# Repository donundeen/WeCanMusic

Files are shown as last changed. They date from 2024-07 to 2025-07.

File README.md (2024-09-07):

# WeCanMusic

WeCanMusic is an open-source hardware and software platform that simplifies the creation of electronic musical instruments from simple found materials and the performance of these instruments by groups of people with no prior musical or performance experience. All sensor input is piped through a system that ensures that the notes produced follow chord changes that can be controlled in real time or composed in advance, allowing integration with live instruments and rock/pop bands. An WeCanMusic Jam Session brings participants together to explore the affordances of low-cost electronic sensors and consider how they can be combined with the materials on hand to create playful objects that generate sound when thrown, touched, bounced, shown colors, etc. These sensors, far from the techno-capitalist ideal of “perfect surveillance devices,” introduce their own noise, flutter and errors, which instead of being corrected, are drawn into dialogue with performers, influencing the aesthetics and acoustics of the performances. Entirely wireless, WeCanMusic performances can happen anywhere, with any number of people, or even with entirely non-human participants. In a new media art world that privileges technical virtuosity, WeCanMusic stubbornly asserts the importance of the amateur, the messy, the joyful. In short, WeCanMusic epowers an entirely different approach to music making, giving everyone a chance to join the jam.

# Included in this repo:

- arduino code to integrate a variety of sensors, on the Arduino Feather ESP32 platform
- Max/MSP patches to control the arduino devices according to a preset-score, and/or a web page allowing real-time chord changes
- NodeJs server which re-implements all Max/MSP features on open-source software, capable of running on a raspberry Pi
- NEW: new arduino code implements the Music Maker (midi synth) Featherwing, so note logic and midi tone production happens on the arduino itself, through attached speakers.
- NEW: Intergration with Pareto Anywhere, allowing the use of Off-the-shelf bluetooth devices as input devices, with audio output through virtual devices running on the server. 

Complete installation instructions coming shortly.

# Live Performances and Media:

- "Paleta De Aguacate, an WeCanMusic Performance", Morelia, Mexico:  https://www.youtube.com/watch?v=Ay2ICAsvL2w&t=2s&ab_channel=DonUndeen 

# In This Repo:

- **arduino**: Arduino files for running on Feather Huzzah ESP32 arduinos. 
  
  - **MaxCompatible**: arduino code for devices that just send thier raw values over UDP to a Max installation (in **PositionalJamAlphaBlast**). I've moved away from this approach to using the more open-source, RPi-based setup in **RPiCompatible**.
  
  - **RPiCompatible**: Arduino code for devices that take their sensor value, turn it into MIDI notes based on the supplied chord changes, and plays the notes using the attached MusicMaker featherwing. It ALSO can send the MIDI note as a makenote message over OSC/UDP, so that another computer could play it via an attached synth. This is useful if you don't have enough MusicMakers, or want to use fancier synths. There will be a sub-folder for each type of device, such as
    
    - **wecanmusic_capacitive**: The version of the device code for handling simple capacitive sensing, on pin 32.
      
      - Note, there are a bunch of files in here, but the only one that should change between types of devices is the one named the same as the folder. All other files should be the same between all devices.
  
  - **Utils:** Useful Utilities
    
    - **curveMaker.maxpat**: sometimes you want to finesse input values in arduino functions, so that an input value is mapped to an output with curve intead of a line, or even a series of curve segments. In this Max patch, you can draw the curve then dump a series of numbers that define the curve, then plug it into the arduino code. **TODO** Build a web interface for drawing curves, or at least selected from a set of pre-created curves.
    
    - **i2c_scanner.ino**:  When working with a bunch of different sensors, sometimes you need to see what i2c channels are in use. That's what this is for
    
    - **SPIFFS_mgmt:** The arduinos use SPIFFS for storing configuration values in non-volative memory. This arduino code helps manage that storage in case things get messy
  
  - **Tests**: Files I made to test things, and may want to refer to later.

- **server**: Files for running the Raspberry Pi server. If you don't need the Local WAP system, then you can run this server code on a Mac, but this setup isn't documented as well. See the README.md file in the **server** folder for installation and usage instructions.

- **VizStudioImplementation**: An implementation of this project that uses Max/MSP for most of the processing. In this setup, the devices simply send their raw values, and Max handles during those values into midi notes according to the chord changes, and sends MIDI values out. In this implmentation, the MIDI values are captured and played by Ableton; the ableton files are also in this folder. I've put aside this version in favor of the more open-source, wireless and headless version using the files in server and arduino folders instead. But there's lots of good stuff in here if you like working with Max.

## Hardware Used:

- Arduino Feather Case, with Battery Case: [Arduino Feather Cases](https://www.tinkercad.com/things/8DuQjJnMVJv-arduino-feather-cases) : this is only slightly modified from the case system created by Adafruit, which you can find here: [Adafruit Feather Box Enclosure by adafruit - Thingiverse](https://www.thingiverse.com/thing:2209964/files). The full assembly instructions and more options for configuration can be found here: [Overview | 3D Printed Case for Adafruit Feather | Adafruit Learning System](https://learn.adafruit.com/3d-printed-case-for-adafruit-feather/) 

- Adafruit HUZZAH32 ESP32 Feather Board: [Adafruit HUZZAH32 – ESP32 Feather ](https://www.adafruit.com/product/3405) 

- Adafruit Music Maker MP3 player and MIDI Synth: [Adafruit Music Maker](https://www.adafruit.com/product/3357) 

- Raspberry Pi 4 (but you can probably use other Pis)

- IQAudio DAC+: Provides much better audio quality than the built-in rpi audio outputs: https://www.pishop.ca/product/iqaudio-dac/ 

#

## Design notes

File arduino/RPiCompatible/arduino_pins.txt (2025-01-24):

/***********************************
Use this is each of the projects in the arduino/RPiCompatible folder
This is an unofficial pinout diagram of the Adafruit Feather Huzza32 (ESP32) board:

https://learn.adafruit.com/adafruit-huzzah32-esp32-feather

For more information about this diagram, see:

https://learn.adafruit.com/adafruit-huzzah32-esp32-feather/pinouts

                                            +-------------------+
                                            | O    | USB |    O |
                                            |      -------   ---|
                                       ~RST | o     3.7/4.2V |  |
                                        3V3 | o  LiPoly Batt |  |
                                         NC | o   USB charge |  |
  config mode button - power switch --- GND | o              ---|
                 power switch---  A0 / DAC2 | o               o | VBAT
                                  A1 / DAC1 | o               o | EN  ------- config mode button
                                    A2 / 34 | o               o | VUSB
                                    A3 / 39 | o               o | 13  / A12 / T4
                                    A4 / 36 | o               o | 12  / A11 / T5
                              T0 /  A5 /  4 | o               o | 27  / A10 / T7
                                   SCK /  5 | o               o | 33  / A9 / T8
                                  MOSI / 18 | o               o | 15  / A8 / T3
                                  MISO / 19 | o               o | 32  / A7 / T9
                                    RX / 16 | o               o | 14  / A6 / T6
                                    TX / 17 | o               o | SCL / 22
                                         21 | o               o | SDA / 23
                                            |                   |
                                            | O               O |
                                            +-------------------+

                             +-----------------------+       
                             | O      | USB |      O |       
                             |        -------        |
                        ~RST | [ ]               |---|
                         3V3 | [ ]               |   | 3.7/4.2V LiPoly Batt (USB charge)
                          NC | [ ]               |---|
                         GND | [ ]                   |
   DAC2 / ADC2 / A0 / GPIO26 | [ ]               [ ] | VBAT / A13
   DAC1 / ADC2 / A1 / GPIO25 | [ ]               [ ] | EN
  NOOUT / ADC1 / A2 / GPIO34 | [ ]               [ ] | VUSB
  NOOUT / ADC1 / A3 / GPIO39 | [ ]               [ ] | GPIO13 / A12 / ADC2 / LED
  NOOUT / ADC1 / A4 / GPIO36 | [ ]               [ ] | GPIO12 / A11 / ADC2
          ADC2 / A5 / GPIO04 | [ ]               [ ] | GPIO27 / A10 / ADC2
                SCK / GPIO05 | [ ]               [ ] | GPIO33 / A9 / ADC1
               MOSI / GPIO18 | [ ]               [ ] | GPIO15 / A8 / ADC2
               MISO / GPIO19 | [ ]               [ ] | GPIO32 / A7 / ADC1
                 RX / GPIO16 | [ ]               [ ] | GPIO14 / A6 / ADC2
                 TX / GPIO17 | [ ]               [ ] | GPIO22 / SCL
                      GPIO21 | [ ]               [ ] | GPIO23 / SDA
                             |                       |
                             | O                   O |
                             +-----------------------+
                             
Power Pins
----------
GND - this is the common ground for all power and logic
BAT - this is the positive voltage to/from the JST jack for the optional Lipoly battery
USB - this is the positive voltage to/from the micro USB jack if connected
EN - this is the 3.3V regulator's enable pin. It's pulled up, so connect to ground to disable the 3.3V regulator
3V - this is the output from the 3.3V regulator. The regulator can supply 500mA peak but half of that is drawn by the ESP32, and it's a fairly power-hungry chip. So if you need a ton of power for stuff like LEDs, motors, etc. Use the USB or BAT pins, and an additional regulator

Logic pins
----------
This is the general purpose I/O pin set for the microcontroller. All logic is 3.3V
The ESP32 runs on 3.3V power and logic, and unless otherwise specified, GPIO pins are not 5V safe!

Serial pins
----------
RX and TX are the additional Serial1 pins, and are not connected to the USB/Serial converter. That means you can use them to connect to UART-devices like GPS's, fingerprint sensors, etc.
The TX pin is the output from the module. The RX pin is the input into the module. Both are 3.3V logic

I2C & SPI pins
----------
You can use the ESP32 to control I2C and SPI devices, sensors, outputs, etc. If using with Arduino, the standard Wire and SPI devices work as you'd expect!
Note that the I2C pins do not have pullup resistors already! You must add them if you want to communicate with an I2C device

GPIO & Analog Pins
----------
GPIO26 - This is also analog input A0 and an analog output DAC2. It uses ADC #2
GPIO25 - This is also analog input A1 and an analog output DAC1. It uses ADC #2
GPIO34 - This is also analog input A2 on ADC #1. Note it is not an output-capable.
GPIO39 - This is also analog input A3 on ADC #1. Note it is not an output-capable.
GPIO36 - This is also analog input A4 on ADC #1. Note it is not an output-capable.
GPIO04 - This is also analog input A5 on ADC #2
GPIO21 - General purpose IO
GPIO13 - This is also an analog input A12 on ADC #2. It's also connected to the red LED next to the USB port
GPIO12 - This is also an analog input A11 on ADC #2. This pin has a pull-down resistor built into it, we recommend using it as an output only, or making sure that the pull-down is not affected during boot.
GPIO27 - This is also an analog input A10 on ADC #2
GPIO33 - This is also an analog input A9 on ADC #1. It can also be used to connect a 32 KHz crystal.
GPIO15 - This is also an analog input A8 on ADC #2
GPIO32 - This is also an analog input A7 on ADC #1. It can also be used to connect a 32 KHz crystal.
GPIO14 - This is also an analog input A6 on ADC #2

There's also an external analog input
A13 - This is general purpose input #35 and also an analog input A13, which is a resistor divider connected to the VBAT line

***********************************/

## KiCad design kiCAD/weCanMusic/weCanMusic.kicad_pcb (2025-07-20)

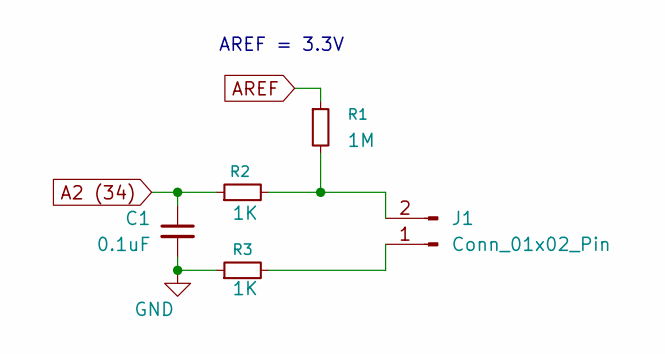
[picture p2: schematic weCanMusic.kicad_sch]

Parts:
C1: 0.1uF; C_0603_1608Metric
J1: Conn_01x02_Pin; PinHeader_1x02_P2.54mm_Vertical
R1: 1M; R_0603_1608Metric
R2, R3: 1K; R_0603_1608Metric

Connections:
A2 (34): C1.1, R2.1
AREF: R1.1
GND: C1.2, R3.1
unnamed: J1.1, R3.2
unnamed: J1.2, R1.2, R2.2

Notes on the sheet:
AREF = 3.3V

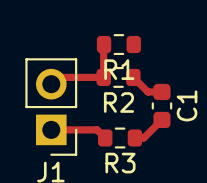
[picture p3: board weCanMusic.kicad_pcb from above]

Board: 2 copper layers, 5 parts (0 on the bottom side), 4 nets.

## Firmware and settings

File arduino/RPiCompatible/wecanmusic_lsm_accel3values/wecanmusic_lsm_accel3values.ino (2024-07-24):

////////////////////////
// NETWORK INCLUDES
/*
 * Required libraries to install in the arduino IDE (use the Library Manager to find and install):
 * https://github.com/Hieromon/PageBuilder : PageBuilder
 * https://github.com/bblanchon/ArduinoJson : ArduinoJson
 * https://github.com/CNMAT/OSC : OSC
 * AutoConnect: https://hieromon.github.io/AutoConnect/index.html : instructions on how to install are here: 
 * follow the instructions under "Install the AutoConnect" if you can't just find it in the Library Manager
 */
// this is all the OSC libraries
#include <SLIPEncodedSerial.h>
#include <OSCData.h>
#include <OSCBundle.h>
#include <OSCBoards.h>
#include <OSCTiming.h>
#include <OSCMessage.h>
#include <OSCMatch.h>
// these the libraries for connecting to WiFi
// based on docs here: https://hieromon.github.io/AutoConnect/gettingstarted.html 
#include <WiFi.h>
// END NETWORK INCLUDES
////////////////////////


// REGEX LIBRARY FOR COMPLEX STRING PARSING
#include <Regexp.h>

// TIMING INCLUDES
#include <AsyncTimer.h> //https://github.com/Aasim-A/AsyncTimer
#include "uClock.h"
// END TIMING INCLUDES

////////////////////////
// CONFIG WEBPAGE INCLUDES
#include <FS.h>                   //this needs to be first, or it all crashes and burns...
#include <WiFiManager.h>          //https://github.com/tzapu/WiFiManager
#ifdef ESP32
  #include <SPIFFS.h>
#endif
#include <ArduinoJson.h>          //https://github.com/bblanchon/ArduinoJson
// END CONFIG WEBPAGE INCLUDES
////////////////////////

// MULTIVALUE SETUP
const int NUM_MULTIVALUES = 3;

////////////////////////////////////
// SENSOR INCLUDES
//gyro code:
// * LSM6DSOX + LIS3MDL FeatherWing : https://www.adafruit.com/product/4565
// * ISM330DHCX + LIS3MDL FeatherWing https://www.adafruit.com/product/4569
// * LSM6DSOX + LIS3MDL Breakout : https://www.adafruit.com/product/4517
// * LSM6DS33 + LIS3MDL Breakout Lhttps://www.adafruit.com/product/4485
// see here: https://learn.adafruit.com/st-9-dof-combo/ard/Users/donundeen/Downloads/TCS3200D/color/color.pdeuino 
/*
 * Libraries to install (include dependencies)
 * OSC
 * Adafruit LSM6DS 
 * Adafruit LIS3MDL
 * AutoConnect (see https://hieromon.github.io/AutoConnect/#installation)
 * 
 */
// SENSOR LIBS/Users/donundeen/Downloads/TCS3200D/TCS3200D/TCS3200D.pde
#include <Adafruit_LSM6DSOX.h>
#include <Adafruit_LIS3MDL.h>
// END SENSOR INCLUDES  
/////////////////////////////////////////

////////////////////////////////
// SENSOR OBJECT CREATION
//Adafruit_LSM6DSOX lsm6ds;
Adafruit_LSM6DSOX lsm6ds;
Adafruit_LIS3MDL lis3mdl;
// END OBJECT CREATION
///////////////////////


///////////////////////////
// DEVICE CONFIGS
// set the accelerometer value to use afor the pitch
// one of:
//    case "gyro.x":
//    case "gyro.y":
//    case "gyro.z":
//    case "accel.x":
//    case "accel.y":
//    case "accel.z":
//    case "mag.x":
//    case "mag.y":
//    case "mag.z":
const int _GYROX = 1;
const int _GYROY = 2;
const int _GYROZ = 3;
const int _ACCELX = 4;
const int _ACCELY = 5;
const int _ACCELZ = 6;
const int _MAGX = 7;
const int _MAGY = 8;
const int _MAGZ = 9;
//int AccelPitchVal[6] = {_GYROX, _GYROY, _GYROZ, _ACCELX, _ACCELY, _ACCELZ}; 
int AccelPitchVal[6] = {_GYROX, _GYROY, _GYROZ, _ACCELX, _ACCELY, _ACCELZ}; 


int SERIALBAUDRATE = 115200;

///////////////////////////////
// MUSIC PERFORMANCE VARIABLES
int notelist[127];
int notelistlength = 0;
int workinglist[6][127]; //MULTIVALUE UPDATE REQUIRED
int workinglistlength[6] = {0,0,0,0,0,0}; //MULTIVALUE UPDATE REQUIRED
// END MUSIC PERFORMANCE VARIABLES
///////////////////////////


// if the device has a synth/speakers attached, set this to true
// if false, it will send a makenote message out over the netework,
// for the server to play.
boolean localSynth = false;

////////////////// SETING UP CONFIG WEBPAGE - FOR WIFI AND OTHER VALUES
//define your default values here, if there are different values in config.json, they are overwritten.
// My values: (in addition to WIFI data)
// wecanmusic_server_ip
// wecanmusic_port
// this_device_name

// wifi autoconnect code
// CONFIG WEBPAGE PINS AND VARS
int resetButtonPin = A0;

char wecanmusic_server_ip[40] = "10.0.0.255";
char wecanmusic_port[6] = "7005";
char this_device_name[16] = "RENAME_ME";
//flag for saving data
bool shouldSaveConfig = true;
/// END SETTING UP CONFIG WEBPAGE VARS
///////////////////////////


/////////////////////////////
// TIMING VARIABLES 
AsyncTimer t;



////////////////////////////////////////////
// NETWORK SPECIFIC VARS - SHOULDN'T CHANGE
/* 
 *  WIFI_MODE_ON set to true to send osc data over WIFI.
 *  When this is true: 
 *  -- if the arduino can't connect to wifi, it will create its own AP, named esp32_ap (pw 12345678)
 *  -- you'll need to connect to that SSID via your phone, and use the interface that pops up on your phone 
 *     to configure the SSID and PW of the router you want to connect to
 *  When WIFI_MODE_ON = false, you need the arduino connected to the laptop, 
 *  and it will send data over serial USB
 */
const boolean WIFI_MODE_ON = true;
/* if we aren't using the auto-configuration process, 
    and we want to hard-code the router's SSID and password here.
    Also set HARDCODE_SSID = true
*/
// remember you can't connect to 5G networks with the arduino. 
bool wifi_connected =false;
/*
 * Sometimes we need to delete the SSIDs that are stored in the config of the arduino.
 * Set this value to TRUE and rerun the arduino, to remove all the stored SSIDs 
 * (aka clear the configuration storage). 
 * Then set it badk to false to start saving new SSID/Passwords
 * 
 */
const boolean DELETE_SSIDS = false;
String thisarduinomac = "";
String thishumanname = "";
String thisarduinoip = "";
//create UDP instance
WiFiUDP udp;
OSCErrorCode error;

// END NETWORK-SPECIFIC VARS
//////////////////////////////////////////////////////////////////////////////



////////////////
// Define the number of pulses per beat
umodular::clock::uClockClass::PPQNResolution PPQNr = uClock.PPQN_96;
int PPQN = 96;

// number of pulses for different common note values.
int WN = PPQN * 4;
int HN = PPQN * 2;
int QN = PPQN;
int N8 = PPQN / 2;
int N16 = PPQN / 4;
int QN3 = HN / 3;
int HN3 = WN / 3;
int N83 = QN / 3;

// array of all notelengths, for picking
int notelengths[] = {WN, HN, HN3, QN, QN3, N8, N83, N16};

// END TIMING VARIABLES
////////////////////////


//////////////////////////////
/// NETWORK CONFIGS  
const boolean HARDCODE_SSID = false; //true; //false;

char *WIFI_SSID = "wecanmusic";// "wecanmusic"; //"JJandJsKewlPad";
char *WIFI_PASSWORD = "";//"wecanmusic";//"wecanmusic"; //"WeL0veLettuce";
char *UDPReceiverIP = "10.0.0.255"; // ip where UDP messages are going
char *presetip = "10.0.0.255"; // in case we just want to force it for testing
int UDPPort = 7005; // the UDP port that Max is listening on
int UDPINPort = 7004; // the UDP port that Max is listening on
// END NETWORK CONFIGS
////////////////////////

// NETWORK+SENSOR CONFIGS
// max size of device name is 19 characters, same as this_device_name, which is the ROOT of the name+ 3 for the number
char DEVICE_NAME[][20] = {"RENAME_MExxxxxxx+xx", "RENAME_MExxxxxxx+xx", "RENAME_MExxxxxxx+xx", "RENAME_MExxxxxxx+xx", "RENAME_MExxxxxxx+xx", "RENAME_MExxxxxxx+xx"};  //MULTIVALUE UPDATE REQUIRED: each value shows as DEVICE_NAME_[index]
char *DEVICE_ID_SUFFIX = "/val";
char DEVICE_ID[][40] = {"/","/","/","/","/","/"};  //MULTIVALUE UPDATE REQUIRED: see above

// NO NETWORK MODE? for testing sensor without network
bool no_network = false;


/////////// MIDI DEFINITIONS /////////////////////

// See http://www.vlsi.fi/fileadmin/datasheets/vs1053.pdf Pg 32 for more!
int midi_voice[6] = {12,12,12,12,12,12}; // see define_configs //MULTIVALUE UPDATE REQUIRED . Also update to bank/program (midi_voice is bank:program)
int midi_bank[6] = {0,0,0,0,0,0}; //MULTIVALUE UPDATE REQUIRED
int midi_program[6] = {1,1,1,1,1,1}; //MULTIVALUE UPDATE REQUIRED

///  END MIDI DEFINITIONS
/////////////////////////////////////////



///////////////////////////////
// MUSIC PERFORMANCE VARIABLES

// These might get changed at start, or during play
int rootMidi[6] = {0,0,0,0,0,0};  //MULTIVALUE UPDATE REQUIRED
int midimin[6] = {32,32,32,32,32,32};  //MULTIVALUE UPDATE REQUIRED
int midimax[6] = {100,100,100,100,100,100}; //MULTIVALUE UPDATE REQUIRED
////// END MUSIC PERFORMANCE VARIABLES  
///////////////////////////////////////

//////////////////////////////
// CURVE VARIABLES

// initial velocity curve is a straight line, extra -1.0 variables are for when we want to make it longer
//float velocitycurve[] = {0., 0.0, 0., 1.0, 1.0, 0.0, -1.0, -1.0 ,-1.0 , -1.0, -1.0 ,-1.0 , -1.0, -1.0 ,-1.0 , -1.0, -1.0 ,-1.0 , -1.0, -1.0 ,-1.0 , -1.0, -1.0 ,-1.0 , -1.0, -1.0 ,-1.0 , -1.0, -1.0 ,-1.0 , -1.0, -1.0 ,-1.0 , -1.0, -1.0 ,-1.0 , -1.0, -1.0 ,-1.0 , -1.0, -1.0 ,-1.0 };
//MULTIVALUE UPDATE REQUIRED
float velocitycurve[][42] = {
  {0., 0., 0., 1., 1., -0.65, 1., 1., -0.65, -1.0, -1.0 ,-1.0 , -1.0, -1.0 ,-1.0 , -1.0, -1.0 ,-1.0 , -1.0, -1.0 ,-1.0 , -1.0, -1.0 ,-1.0 , -1.0, -1.0 ,-1.0 , -1.0, -1.0 ,-1.0 , -1.0, -1.0 ,-1.0 , -1.0, -1.0 ,-1.0 , -1.0, -1.0 ,-1.0 , -1.0, -1.0 ,-1.0 },
  {0., 0., 0., 1., 1., -0.65, 1., 1., -0.65, -1.0, -1.0 ,-1.0 , -1.0, -1.0 ,-1.0 , -1.0, -1.0 ,-1.0 , -1.0, -1.0 ,-1.0 , -1.0, -1.0 ,-1.0 , -1.0, -1.0 ,-1.0 , -1.0, -1.0 ,-1.0 , -1.0, -1.0 ,-1.0 , -1.0, -1.0 ,-1.0 , -1.0, -1.0 ,-1.0 , -1.0, -1.0 ,-1.0 },
  {0., 0., 0., 1., 1., -0.65, 1., 1., -0.65, -1.0, -1.0 ,-1.0 , -1.0, -1.0 ,-1.0 , -1.0, -1.0 ,-1.0 , -1.0, -1.0 ,-1.0 , -1.0, -1.0 ,-1.0 , -1.0, -1.0 ,-1.0 , -1.0, -1.0 ,-1.0 , -1.0, -1.0 ,-1.0 , -1.0, -1.0 ,-1.0 , -1.0, -1.0 ,-1.0 , -1.0, -1.0 ,-1.0 },
  {0., 0., 0., 1., 1., -0.65, 1., 1., -0.65, -1.0, -1.0 ,-1.0 , -1.0, -1.0 ,-1.0 , -1.0, -1.0 ,-1.0 , -1.0, -1.0 ,-1.0 , -1.0, -1.0 ,-1.0 , -1.0, -1.0 ,-1.0 , -1.0, -1.0 ,-1.0 , -1.0, -1.0 ,-1.0 , -1.0, -1.0 ,-1.0 , -1.0, -1.0 ,-1.0 , -1.0, -1.0 ,-1.0 },
  {0., 0., 0., 1., 1., -0.65, 1., 1., -0.65, -1.0, -1.0 ,-1.0 , -1.0, -1.0 ,-1.0 , -1.0, -1.0 ,-1.0 , -1.0, -1.0 ,-1.0 , -1.0, -1.0 ,-1.0 , -1.0, -1.0 ,-1.0 , -1.0, -1.0 ,-1.0 , -1.0, -1.0 ,-1.0 , -1.0, -1.0 ,-1.0 , -1.0, -1.0 ,-1.0 , -1.0, -1.0 ,-1.0 },
  {0., 0., 0., 1., 1., -0.65, 1., 1., -0.65, -1.0, -1.0 ,-1.0 , -1.0, -1.0 ,-1.0 , -1.0, -1.0 ,-1.0 , -1.0, -1.0 ,-1.0 , -1.0, -1.0 ,-1.0 , -1.0, -1.0 ,-1.0 , -1.0, -1.0 ,-1.0 , -1.0, -1.0 ,-1.0 , -1.0, -1.0 ,-1.0 , -1.0, -1.0 ,-1.0 , -1.0, -1.0 ,-1.0 }
};
float velocitycurvelength[] = {6,6,6,6,6,6}; 
String velocitycurvename[6] = {"curve_logup","curve_logup","curve_logup","curve_logup","curve_logup","curve_logup"};

// a collection of useful curves:
float curve_str8up[]       = {0., 0., 0., 1., 1., 0.};
float curve_str8dn[]       = {0., 1., 0., 1., 0., 0.};
float curve_logup[]        = {0., 0., 0., 1., 1., -0.65};
float curve_logdn[]        = {0., 1., 0., 1., 0., -0.65}; // not sure if this is right
float curve_expup[]        = {0., 0., 0., 1., 1., 0.65};
float curve_expdn[]        = {0., 1., 0., 1., 0., 0.65}; // not sure if this is right
float curve_str8upthresh[] = {0., 0., 0., 0.05, 0., 0., 1., 1., 0.};
float curve_str8dnthresh[] = {0., 1., 0., 0.95, 0., 0., 1., 0., 0., 1., 0., 0.};
float curve_logupthresh[]  = {0., 0., 0., 0.05, 0., 0., 1., 1., -0.65};
float curve_logdnthresh[]  = {0., 1., 0., 0.95, 0., -0.65, 1., 0., -0.65};


/////////////////////////////
// TIMING VARIABLES 
int bpm = 120;

/////////////////////////////
// Sensor scaling variables
float minVal[6] = {100000.0, 100000.0, 100000.0, 100000.0, 100000.0, 100000.0}; //MULTIVALUE UPDATE REQUIRED
float maxVal[6] = {-1.0, -1.0, -1.0, -1.0, -1.0, -1.0};    //MULTIVALUE UPDATE REQUIRED
float changeMin[6] = {10000.0, 10000.0, 10000.0, 10000.0, 10000.0, 10000.0};  //MULTIVALUE UPDATE REQUIRED
float changeMax[6] = {-1.0, -1.0, -1.0, -1.0, -1.0, -1.0}; //MULTIVALUE UPDATE REQUIRED

float elasticMinMaxScale = .005; // if true, then the min and max values used for dynamic scaling slowly come closer together, 
                                // so that a rate large value over time will get smoothed out
                                // set to 0 to disable //MULTIVALUE UPDATE REQUIRED

////////////////////////////////////
// SENSOR PROCESSING GLOBALS
bool firstSense[6] = {false, false, false, false, false, false}; //MULTIVALUE UPDATE REQUIRED
int ADCRaw[6] = {-1, -1, -1, -1, -1, -1};          //MULTIVALUE UPDATE REQUIRED. ALSO rename to sensorInputVal or something
float changerate[6] = {-1.0, -1.0, -1.0, -1.0, -1.0, -1.0}; //MULTIVALUE UPDATE REQUIRED
float prevChangeVal[6] = {-1.0, -1.0, -1.0, -1.0, -1.0, -1.0};  //MULTIVALUE UPDATE REQUIRED
int prevChangeTime[6] = {-1, -1, -1, -1, -1, -1} ;     //MULTIVALUE UPDATE REQUIRED


void reset_minmax(int vindex){  //MULTIVALUE UPDATE REQUIRED
  minVal[vindex] = 100000.0; //MULTIVALUE UPDATE REQUIRED
  maxVal[vindex] = -1.0;      //MULTIVALUE UPDATE REQUIRED
  changeMin[vindex] = 10000.0;  //MULTIVALUE UPDATE REQUIRED
  changeMax[vindex] = -1.0;     //MULTIVALUE UPDATE REQUIRED
}




void sensor_setup(){
  delay(1000);
  Serial.println("setup");

  // for incoming UDP
  //  SLIPSerial.begin(115200);

  pinMode(BUILTIN_LED, OUTPUT);

  // gyro/accel stuff
  bool lsm6ds_success, lis3mdl_success;

  // hardware I2C mode, can pass in address & alt Wire

  lsm6ds_success = lsm6ds.begin_I2C();
  lis3mdl_success = lis3mdl.begin_I2C();

  if (!lsm6ds_success){
    Serial.println("Failed to find LSM6DS chip");
  }
  if (!lis3mdl_success){
    Serial.println("Failed to find LIS3MDL chip");
  }
  if (!(lsm6ds_success && lis3mdl_success)) {
    while (1) {
      delay(10);
    }
  }

  Serial.println("LSM6DS and LIS3MDL Found!");

  // lsm6ds.setAccelRange(LSM6DS_ACCEL_RANGE_2_G);
  Serial.print("Accelerometer range set to: ");
  switch (lsm6ds.getAccelRange()) {
  case LSM6DS_ACCEL_RANGE_2_G:
    Serial.println("+-2G");
    break;
  case LSM6DS_ACCEL_RANGE_4_G:
    Serial.println("+-4G");
    break;
  case LSM6DS_ACCEL_RANGE_8_G:
    Serial.println("+-8G");
    break;
  case LSM6DS_ACCEL_RANGE_16_G:
    Serial.println("+-16G");
    break;
  }

  // lsm6ds.setAccelDataRate(LSM6DS_RATE_12_5_HZ);
  Serial.print("Accelerometer data rate set to: ");
  switch (lsm6ds.getAccelDataRate()) {
  case LSM6DS_RATE_SHUTDOWN:
    Serial.println("0 Hz");
    break;
  case LSM6DS_RATE_12_5_HZ:
    Serial.println("12.5 Hz");
    break;
  case LSM6DS_RATE_26_HZ:
    Serial.println("26 Hz");
    break;
  case LSM6DS_RATE_52_HZ:
    Serial.println("52 Hz");
    break;
  case LSM6DS_RATE_104_HZ:
    Serial.println("104 Hz");
    break;
  case LSM6DS_RATE_208_HZ:
    Serial.println("208 Hz");
    break;
  case LSM6DS_RATE_416_HZ:
    Serial.println("416 Hz");
    break;
  case LSM6DS_RATE_833_HZ:
    Serial.println("833 Hz");
    break;
  case LSM6DS_RATE_1_66K_HZ:
    Serial.println("1.66 KHz");
    break;
  case LSM6DS_RATE_3_33K_HZ:
    Serial.println("3.33 KHz");
    break;
  case LSM6DS_RATE_6_66K_HZ:
    Serial.println("6.66 KHz");
    break;
  }

  // lsm6ds.setGyroRange(LSM6DS_GYRO_RANGE_250_DPS );
  Serial.print("Gyro range set to: ");
  switch (lsm6ds.getGyroRange()) {
  case LSM6DS_GYRO_RANGE_125_DPS:
    Serial.println("125 degrees/s");
    break;
  case LSM6DS_GYRO_RANGE_250_DPS:
    Serial.println("250 degrees/s");
    break;
  case LSM6DS_GYRO_RANGE_500_DPS:
    Serial.println("500 degrees/s");
    break;
  case LSM6DS_GYRO_RANGE_1000_DPS:
    Serial.println("1000 degrees/s");
    break;
  case LSM6DS_GYRO_RANGE_2000_DPS:
    Serial.println("2000 degrees/s");
    break;
  case ISM330DHCX_GYRO_RANGE_4000_DPS:
    Serial.println("4000 degrees/s");
    break;
  }
  // lsm6ds.setGyroDataRate(LSM6DS_RATE_12_5_HZ);
  Serial.print("Gyro data rate set to: ");
  switch (lsm6ds.getGyroDataRate()) {
  case LSM6DS_RATE_SHUTDOWN:
    Serial.println("0 Hz");
    break;
  case LSM6DS_RATE_12_5_HZ:
    Serial.println("12.5 Hz");
    break;
  case LSM6DS_RATE_26_HZ:
    Serial.println("26 Hz");
    break;
  case LSM6DS_RATE_52_HZ:
    Serial.println("52 Hz");
    break;
  case LSM6DS_RATE_104_HZ:
    Serial.println("104 Hz");
    break;
  case LSM6DS_RATE_208_HZ:
    Serial.println("208 Hz");
    break;
  case LSM6DS_RATE_416_HZ:
    Serial.println("416 Hz");
    break;
  case LSM6DS_RATE_833_HZ:
    Serial.println("833 Hz");
    break;
  case LSM6DS_RATE_1_66K_HZ:
    Serial.println("1.66 KHz");
    break;
  case LSM6DS_RATE_3_33K_HZ:
    Serial.println("3.33 KHz");
    break;
  case LSM6DS_RATE_6_66K_HZ:
    Serial.println("6.66 KHz");
    break;
  }

  lis3mdl.setDataRate(LIS3MDL_DATARATE_155_HZ);
  // You can check the datarate by looking at the frequency of the DRDY pin
  Serial.print("Magnetometer data rate set to: ");
  switch (lis3mdl.getDataRate()) {
    case LIS3MDL_DATARATE_0_625_HZ: Serial.println("0.625 Hz"); break;
    case LIS3MDL_DATARATE_1_25_HZ: Serial.println("1.25 Hz"); break;
    case LIS3MDL_DATARATE_2_5_HZ: Serial.println("2.5 Hz"); break;
    case LIS3MDL_DATARATE_5_HZ: Serial.println("5 Hz"); break;
    case LIS3MDL_DATARATE_10_HZ: Serial.println("10 Hz"); break;
    case LIS3MDL_DATARATE_20_HZ: Serial.println("20 Hz"); break;
    case LIS3MDL_DATARATE_40_HZ: Serial.println("40 Hz"); break;
    case LIS3MDL_DATARATE_80_HZ: Serial.println("80 Hz"); break;
    case LIS3MDL_DATARATE_155_HZ: Serial.println("155 Hz"); break;
    case LIS3MDL_DATARATE_300_HZ: Serial.println("300 Hz"); break;
    case LIS3MDL_DATARATE_560_HZ: Serial.println("560 Hz"); break;
    case LIS3MDL_DATARATE_1000_HZ: Serial.println("1000 Hz"); break;
  }

  lis3mdl.setRange(LIS3MDL_RANGE_4_GAUSS);
  Serial.print("Range set to: ");
  switch (lis3mdl.getRange()) {
    case LIS3MDL_RANGE_4_GAUSS: Serial.println("+-4 gauss"); break;
    case LIS3MDL_RANGE_8_GAUSS: Serial.println("+-8 gauss"); break;
    case LIS3MDL_RANGE_12_GAUSS: Serial.println("+-12 gauss"); break;
    case LIS3MDL_RANGE_16_GAUSS: Serial.println("+-16 gauss"); break;
  }

  lis3mdl.setPerformanceMode(LIS3MDL_MEDIUMMODE);
  Serial.print("Magnetometer performance mode set to: ");
  switch (lis3mdl.getPerformanceMode()) {
    case LIS3MDL_LOWPOWERMODE: Serial.println("Low"); break;
    case LIS3MDL_MEDIUMMODE: Serial.println("Medium"); break;
    case LIS3MDL_HIGHMODE: Serial.println("High"); break;
    case LIS3MDL_ULTRAHIGHMODE: Serial.println("Ultra-High"); break;
  }

  lis3mdl.setOperationMode(LIS3MDL_CONTINUOUSMODE);
  Serial.print("Magnetometer operation mode set to: ");
  // Single shot mode will complete conversion and go into power down
  switch (lis3mdl.getOperationMode()) {
    case LIS3MDL_CONTINUOUSMODE: Serial.println("Continuous"); break;
    case LIS3MDL_SINGLEMODE: Serial.println("Single mode"); break;
    case LIS3MDL_POWERDOWNMODE: Serial.println("Power-down"); break;
  }

  lis3mdl.setIntThreshold(500);
  lis3mdl.configInterrupt(false, false, true, // enable z axis
                          true, // polarity
                          false, // don't latch
                          true); // enabled!

  // Start the loops here, not in the loop() function
  t.setInterval(sensor_loop, 10);
  sensor_loop();  //MULTIVALUE UPDATE REQUIRED
//  t.setInterval(changerate_loop, 100);
  changerate_loop();  //MULTIVALUE UPDATE REQUIRED
  note_loop();  //MULTIVALUE UPDATE REQUIRED


}

void note_loop(){
  for (int i = 0 ; i < NUM_MULTIVALUES; i++){
    note_loop(i);
  }
}

void note_loop(int vindex){
  if(!firstSense[vindex]){   //MULTIVALUE UPDATE REQUIRED
    // sensor hasn't sensed yet, skip this
    return;
  }
  changerate_loop(vindex);  //MULTIVALUE UPDATE REQUIRED
  char pbuf[100];
  sprintf(pbuf, "looppre: in:%d  min %f max %f", ADCRaw[vindex], minVal[vindex], maxVal[vindex]);
//  Serial.println(pbuf);
  float value = dyn_rescale(ADCRaw[vindex], &minVal[vindex], &maxVal[vindex], 0.0, 1.0);  //MULTIVALUE UPDATE REQUIRED
  sprintf(pbuf, "loop: in:%d scaled:%f min %f max %f", ADCRaw, value, minVal, maxVal);
//  Serial.println(pbuf);
  int midipitch    = derive_pitch(vindex, value);  //MULTIVALUE UPDATE REQUIRED
  int midivelocity = derive_velocity(vindex, ADCRaw[vindex]);  //MULTIVALUE UPDATE REQUIRED
  int mididuration = derive_duration(vindex, value);    //MULTIVALUE UPDATE REQUIRED
  sprintf(pbuf, "      in:%d scaled:%f p:%d v:%d d:%d", ADCRaw[vindex], value, midipitch, midivelocity, mididuration);
//  Serial.println(pbuf);
  // this will also make it monophonic:
  if(localSynth){
    midiMakeNote(vindex, midipitch, midivelocity, mididuration);  //MULTIVALUE UPDATE REQUIRED
  }else{
    sendMakeNote(vindex, midipitch, midivelocity, mididuration);  //MULTIVALUE UPDATE REQUIRED
  }
  t.setTimeout(note_loop, mididuration); // but changing the mididuration in this function could make notes overlap, so creeat space between notes. Or we make this a sensor-controlled variable as well
}

void sensor_loop(){
  for(int vindex = 0 ; vindex < NUM_MULTIVALUES; vindex++){
    sensor_loop(vindex);
  }
}
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
void loop() {  
  // everything else should be handled as async calls
  if(!no_network){
    network_loop();
  }  
  udp_loop();
  t.handle();
//  sensor_loop(); // moving this into sensor_setup, with a setTimeout function to make the looping happen
}
// END SETUP AND LOOP FUNCTIONS
/////////////////////////////////

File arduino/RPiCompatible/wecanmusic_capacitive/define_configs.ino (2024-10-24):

//////////////////////////
// DEFINE CONFIGS FILE
///*************************
// Defining all the config values
// functions that are specific to different config values

/* make an array of defined vonfig vars, sorta like
["var1","int",
"var2", "string",
"var3", "intarray",
etc...]
*/

//Variable List
// int midi_voice = 12;
// int midimin
// int midimax
// int midi_nlen
// int midi_vol

void config_setup(){
  for (int vindex = 0 ; vindex < NUM_MULTIVALUES; vindex++){
    config_setup(vindex);
  }
}


void config_setup(int vindex){   //MULTIVALUE UPDATE REQUIRED
  // midi_voice just split out into bank/program when received.
 // midi_voice[vindex] = getStoredConfigValInt(vindex, "midi_voice");  //MULTIVALUE UPDATE REQUIRED
  midi_bank[vindex] = getStoredConfigValInt(vindex, "midi_bank");  //MULTIVALUE UPDATE REQUIRED
  midi_program[vindex] = getStoredConfigValInt(vindex, "midi_program");  //MULTIVALUE UPDATE REQUIRED
  midimin[vindex] = getStoredConfigValInt(vindex, "midimin");  //MULTIVALUE UPDATE REQUIRED
  midimax[vindex] = getStoredConfigValInt(vindex, "midimax");  //MULTIVALUE UPDATE REQUIRED
  midi_notelength[vindex] = getStoredConfigValInt(vindex, "midi_nlen");  //MULTIVALUE UPDATE REQUIRED
  midi_vol[vindex] = getStoredConfigValInt(vindex, "midi_vol");  //MULTIVALUE UPDATE REQUIRED
  Serial.println("setting midi bank and program and note length");
  midiSetChannelBank(0, midi_bank[vindex]);  //MULTIVALUE UPDATE REQUIRED
  midiSetChannelProgram(0, midi_program[vindex]);  //MULTIVALUE UPDATE REQUIRED
}


void routeDeviceMsg(OSCMessage &msg, int addrOffset ){  //MULTIVALUE UPDATE REQUIRED
  Serial.println("devicemsg");
  char devroute[100];
  char address[32];
  msg.getAddress(address);
  Serial.println (address);
  for(int vindex = 0; vindex < NUM_MULTIVALUES; vindex++){
    sprintf(devroute, "/%s/config", DEVICE_NAME[vindex]);   //MULTIVALUE UPDATE REQUIRED
    Serial.println(devroute);
    msg.route(devroute, routeConfigVal);
  }
  Serial.println("done routeDeviceMsg");
}


void routeConfigVal(OSCMessage &msg, int addrOffset ){
  Serial.println("configvar");
  char devroute[100];


  for (int vindex = 0; vindex < NUM_MULTIVALUES; vindex++){

    // one of these for each variable
    sprintf(devroute,"/%s/config/somevar",DEVICE_NAME[vindex]);  //MULTIVALUE UPDATE REQUIRED
    msg.route(devroute, routeConfig_somevar);  //MULTIVALUE UPDATE REQUIRED

    // midi_vocie
    sprintf(devroute,"/%s/config/midi_voice",DEVICE_NAME[vindex]);  //MULTIVALUE UPDATE REQUIRED
    msg.route(devroute, routeConfig_midi_voice);  //MULTIVALUE UPDATE REQUIRED

    // also add bank and program (transition to bank and program from midi_voice)
    sprintf(devroute,"/%s/config/midi_program",DEVICE_NAME[vindex]);  //MULTIVALUE UPDATE REQUIRED
    msg.route(devroute, routeConfig_midi_program);  //MULTIVALUE UPDATE REQUIRED
    sprintf(devroute,"/%s/config/midi_bank",DEVICE_NAME[vindex]);  //MULTIVALUE UPDATE REQUIRED
    msg.route(devroute, routeConfig_midi_bank);  //MULTIVALUE UPDATE REQUIRED

    sprintf(devroute,"/%s/config/midimin",DEVICE_NAME[vindex]);  //MULTIVALUE UPDATE REQUIRED
    msg.route(devroute, routeConfig_midimin);  //MULTIVALUE UPDATE REQUIRED

    sprintf(devroute,"/%s/config/midimax",DEVICE_NAME[vindex]);   //MULTIVALUE UPDATE REQUIRED
    msg.route(devroute, routeConfig_midimax);  //MULTIVALUE UPDATE REQUIRED

    sprintf(devroute,"/%s/config/midi_nlen",DEVICE_NAME[vindex]);   //MULTIVALUE UPDATE REQUIRED
    msg.route(devroute, routeConfig_midi_notelength);  //MULTIVALUE UPDATE REQUIRED

    sprintf(devroute,"/%s/config/midi_vol",DEVICE_NAME[vindex]);   //MULTIVALUE UPDATE REQUIRED
    msg.route(devroute, routeConfig_midi_vol);  //MULTIVALUE UPDATE REQUIRED

    sprintf(devroute,"/%s/config/velocitycurve",DEVICE_NAME[vindex]);  //MULTIVALUE UPDATE REQUIRED
    msg.route(devroute, routeConfig_velocitycurve);  //MULTIVALUE UPDATE REQUIRED


    // reset system (max/mins, etc)
    sprintf(devroute,"/%s/config/reset",DEVICE_NAME[vindex]);  //MULTIVALUE UPDATE REQUIRED
    msg.route(devroute, routeConfig_reset);  //MULTIVALUE UPDATE REQUIRED
  }
  Serial.println("end RoutConfigVal");
}


int extractVindexFromRoute(char* address){
  // format will be /some_devis_name_2/config/varname
  // and we want the number 2 (always one digit)
  // regex "/[^/]+_(%d)/.*"
  MatchState ms;
  Serial.println(address);
  char regexp[20]  = "/[^/]+_(%d)/.*";
  Serial.println(regexp);
  ms.Target(address);
  char result = ms.Match(regexp);
  if(result == REGEXP_MATCHED){
      char buf[3];
      ms.GetCapture(buf, 0);
      int vindex = atoi(buf);
      Serial.println("matched");
      Serial.println(vindex);
      return vindex;
  }else if (result == REGEXP_NOMATCH){ // no match
    Serial.println("NO MATCH");
    return -1;
  }else{ // some other error
    Serial.println("other match error");
    return -1;
  }
  return -1;

}
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

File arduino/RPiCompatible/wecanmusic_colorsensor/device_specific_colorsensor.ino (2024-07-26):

//////////////////////////////
// DEVICE-SPECIFIC CONFIG VARS
// MULTIVALUE SETUP
const int DEVICE_NUM_MULTIVALUES = 1;

// TCS230 or TCS3200 pins wiring to Arduino
#define S0 27
#define S1 33
#define S2 15
#define S3 32
#define sensorOut A2


// Stores frequency read by the photodiodes
int redFrequency = 0;
int greenFrequency = 0;
int blueFrequency = 0;

// calibration values 
int redlow = 60;
int redhigh = 800;
int greenlow = 75;
int greenhigh = 3000;
int bluelow = 50;
int bluehigh = 700;

// Stores the red. green and blue colors
int redColor = 0;
int greenColor = 0;
int blueColor = 0;




// END DEVICE-SPECIFIC CONFIG VARS
//////////////////////////////


////////////////////////////////////////////////////
/////////////////////////////
// DEVICE SPECIFIC FUNCTIONS

void sensor_setup_device(){

  // Setting the outputs
  pinMode(S0, OUTPUT);
  pinMode(S1, OUTPUT);
  pinMode(S2, OUTPUT);
  pinMode(S3, OUTPUT);
  
  // Setting the sensorOut as an input
  pinMode(sensorOut, INPUT);
  
  // Setting frequency scaling to 20%
  digitalWrite(S0,HIGH);
  digitalWrite(S1,LOW);
}


// sensor_loop must:
// - set ADCRaw[vindex] with the read sensor value
// - set firstSense[vindex] to true

void sensor_loop(int vindex){

 // Setting RED (R) filtered photodiodes to be read
  digitalWrite(S2,LOW);
  digitalWrite(S3,LOW);
  
  // Reading the output frequency
  redFrequency = pulseIn(sensorOut, LOW);
  // Remaping the value of the RED (R) frequency from 0 to 255
  // You must replace with your own values. Here's an example: 
  // redColor = map(redFrequency, 70, 120, 255,0);
  redColor = map(redFrequency, redlow, redhigh, 255,0);

  // Printing the RED (R) value
  Serial.print("R = ");
  Serial.print(redFrequency);
  Serial.print("|");
  Serial.print(redColor);
  
  // Setting GREEN (G) filtered photodiodes to be read
  digitalWrite(S2,HIGH);
  digitalWrite(S3,HIGH);
  
  // Reading the output frequency
  greenFrequency = pulseIn(sensorOut, LOW);
  greenColor = map(greenFrequency, greenlow, greenhigh, 255, 0);

  // Printing the GREEN (G) value  
  Serial.print(" G = ");
  Serial.print(greenFrequency);
  Serial.print("|");
  Serial.print(greenColor);
   
  // Setting BLUE (B) filtered photodiodes to be read
  digitalWrite(S2,LOW);
  digitalWrite(S3,HIGH);
  
  // Reading the output frequency
  blueFrequency = pulseIn(sensorOut, LOW);
  blueColor = map(blueFrequency, bluelow, bluehigh, 255, 0);

  // Printing the BLUE (B) value   
  Serial.print(" B = ");
  Serial.print(blueFrequency);
  Serial.print("|");
  Serial.println(blueColor);
  
  double redf = float(redColor) / 255.0;
  double greenf = float(greenColor) / 255.0;
  double bluef = float(blueColor) / 255.0;
  double hsl[3];
  rgbToHsl(redf, greenf, bluef, hsl);
  /*
  Serial.print("H:" );
  Serial.print(hsl[0]);
  Serial.print(" S:" );
  Serial.print(hsl[1]);
  Serial.print(" L:" );
  Serial.println(hsl[2]);
  */

  // raw value is the Hue (not sure of the range, so let's multiply before casting to int)
  // this code supports multivalue, but here we only write to the first ADCRAw value
  ADCRaw[0] = (int)(hsl[0] * 1000);
  //ADCRaw = analogRead(sensorPin);

  Serial.println("read value");

  Serial.println(ADCRaw[0]);
  Serial.println(hsl[0]);
  Serial.println(hsl[1]);
  Serial.println(hsl[2]);

  firstSense[vindex] = true;   //MULTIVALUE UPDATE REQUIRED

  /*
  if(!no_network){
    sendOSCUDP(ADCRaw);
  }
  */
  // should be 10
  //delay(10); // removing when using timeouts
}


/**
 * Converts an RGB color value to HSL. Conversion formula
 * adapted from http://en.wikipedia.org/wiki/HSL_color_space.
 * Assumes r, g, and b are contained in the set [0, 255] and
 * returns h, s, and l in the set [0, 1].
 *
 * @param   Number  r       The red color value
 * @param   Number  g       The green color value
 * @param   Number  b       The blue color value
 * @return  Array           The HSL representation
 */
void rgbToHsl(double rd, double gd, double bd, double hsl[]) { 

    double max = threeway_max(rd, gd, bd);
    double min = threeway_min(rd, gd, bd);
    double h, s, l = (max + min) / 2;

    if (max == min) {
        h = s = 0; // achromatic
    } else {
        double d = max - min;
        s = l > 0.5 ? d / (2 - max - min) : d / (max + min);
        if (max == rd) {
            h = (gd - bd) / d + (gd < bd ? 6 : 0);
        } else if (max == gd) {
            h = (bd - rd) / d + 2;
        } else if (max == bd) {
            h = (rd - gd) / d + 4;
        }
        h /= 6;
    }
    hsl[0] = h;
    hsl[1] = s;
    hsl[2] = l;
}


double threeway_max(double a, double b, double c) {
    return max(a, max(b, c));
}

double threeway_min(double a, double b, double c) {
    return min(a, min(b, c));
}



// END DEVICE SPECIFIC FUNCTIONS
/////////////////////////////



int get_num_multivalues(){
    return DEVICE_NUM_MULTIVALUES;
}
